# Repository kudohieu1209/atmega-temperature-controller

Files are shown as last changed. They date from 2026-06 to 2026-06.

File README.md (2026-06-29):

# ATmega16 Temperature Controller (LM35)

Bộ điều khiển nhiệt độ dùng vi điều khiển **ATmega16** và cảm biến **LM35**, viết bằng
**CodeVisionAVR**. Đọc nhiệt độ qua ADC, hiển thị lên LCD 16x2, và tự động bật/tắt
**quạt** và **đèn** qua relay theo ngưỡng nhiệt độ cài đặt.

## Tính năng

- Đọc nhiệt độ thực tế qua **ADC0 (PA0)** từ cảm biến **LM35** (10 mV/°C), Vref nội
  2.56V, độ phân giải 8-bit.
- **Mẹo thang đo:** `2.56V / 256 = 10 mV = đúng 1°C mỗi bước ADC`, nên giá trị `ADCH`
  đọc ra **chính là nhiệt độ °C** (dải 0–255 phủ tốt 0–100°C) — không cần công thức quy đổi.
- Hiển thị nhiệt độ **thực tế** và nhiệt độ **cài đặt** trên LCD 16x2.
- Điều khiển relay:
  - `temp > ngưỡng` → **bật quạt**, tắt đèn (làm mát).
  - `temp <= ngưỡng` → tắt quạt, **bật đèn** (sưởi).
- Cài đặt ngưỡng bằng 3 nút: UP / DOWN / RESET.
- Lưu ngưỡng cài đặt vào **EEPROM** → giữ nguyên sau khi mất điện.

## Sơ đồ chân

| Chân  | Chức năng |
|---|---|
| PA0 | Đầu vào ADC (cảm biến nhiệt độ) |
| PB0 | Nút UP — tăng ngưỡng |
| PB1 | Nút DOWN — giảm ngưỡng |
| PB2 | Relay FAN (quạt) — output |
| PB3 | Relay LIGHT (đèn) — output |
| PB4 | Nút RESET — về mặc định (25°C) |
| PORTC/PORTD | LCD 16x2 (theo cấu hình CodeWizard) |

> PB0, PB1, PB4 dùng điện trở kéo lên nội (active-low — nhấn = mức 0).

## Sơ đồ mạch (Proteus)

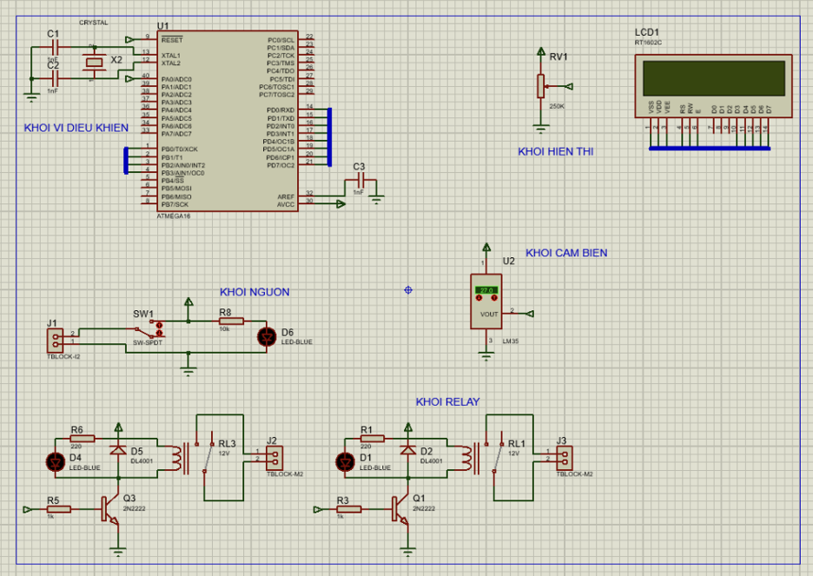
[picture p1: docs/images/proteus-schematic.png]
Sơ đồ mạch Proteus


Sơ đồ gồm các khối: vi điều khiển (ATmega16 + thạch anh), hiển thị (LCD1602 +
biến trở chỉnh tương phản), cảm biến (LM35), nguồn (công tắc + LED báo) và relay
(2 relay 12V kích qua transistor 2N2222 cho quạt/đèn).

File thiết kế PCB/sơ đồ nguyên lý gốc (Altium Designer) nằm trong
[`altium_schematic/`](altium_schematic/):

- `Sheet2.SchDoc` — sơ đồ nguyên lý
- `PCB2.PcbDoc` — layout mạch in

## Cấu trúc thư mục

```
atmega-temperature-controller/
├── README.md
├── src/
│   └── main.c                  # Mã nguồn chính
├── docs/
│   ├── hardware.md             # Mô tả phần cứng & ghi chú
│   └── images/
│       └── proteus-schematic.png   # Sơ đồ nguyên lý Proteus
└── altium_schematic/
    ├── Sheet2.SchDoc            # Sơ đồ nguyên lý (Altium Designer)
    └── PCB2.PcbDoc              # Layout PCB (Altium Designer)
```

## Biên dịch

Dự án dùng các thư viện riêng của CodeVisionAVR (`io.h`, `alcd.h`, `delay.h`).

1. Mở **CodeVisionAVR**, tạo project mới (hoặc dùng CodeWizardAVR).
2. Chọn chip **ATmega16** (kit hỗ trợ cả ATmega32 cùng chân đế) và tần số thạch anh.
3. Thêm `src/main.c` vào project.
4. Cấu hình LCD theo bảng chân ở trên, bật ADC với Vref nội 2.56V, ADLAR.
5. Build → nạp file `.hex` xuống chip (qua USBasp / mô phỏng Proteus).

## Ghi chú

- Với cấu hình **Vref 2.56V + 8-bit + LM35**, `ADCH` đọc ra trực tiếp là °C
  (1 LSB = 10 mV = 1°C). Nếu đổi Vref hoặc cảm biến khác thì phải đổi công thức quy đổi.
- LM35 chỉ đo dương (0°C trở lên); cấp nguồn 5V cho LM35, chân OUT nối PA0/ADC0.
- Ký tự `°` dùng mã `\xDF` của bộ ký tự HD44780 trên LCD.

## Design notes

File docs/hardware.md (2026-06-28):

# Phần cứng & Ghi chú kỹ thuật

## Sơ đồ nguyên lý
Xem sơ đồ mô phỏng Proteus tại [images/proteus-schematic.png](images/proteus-schematic.png):
các khối vi điều khiển, hiển thị (LCD1602), cảm biến (LM35), nguồn và relay.

## Khối nguồn / vi điều khiển
- MCU: **ATmega16** (kit AVR hỗ trợ cả ATmega32 cùng chân đế).
- Thạch anh ngoài tùy chọn; cấu hình tần số khớp với `delay.h`.

## Khối cảm biến — LM35
- Cảm biến nhiệt độ analog tuyến tính, hệ số **10 mV/°C** (vd. 250 mV = 25°C).
- Chân: `1 = VCC (5V)`, `2 = OUT → PA0/ADC0`, `3 = GND`.
- Chỉ đo dải dương (≥ 0°C); đầu ra trở kháng thấp, nối thẳng vào ADC được.

## Khối ADC (đọc LM35)
- Kênh: **ADC0 (PA0)**.
- Vref: nội bộ **2.56V** (`REFS1=1, REFS0=1`).
- `ADLAR = 1` → kết quả căn trái, đọc 8-bit từ thanh ghi `ADCH`.
- Prescaler: `ADPS2 | ADPS1` = chia 64.
- **Thang đo trực tiếp:** `2.56V / 256 = 10 mV = 1°C/LSB`, trùng đúng hệ số LM35,
  nên `temp = ADCH` cho ra °C mà không cần nhân/chia.

## Khối hiển thị
- LCD ký tự **16x2** (HD44780), thư viện `alcd.h`.
- Khởi tạo: `lcd_init(16)`.
- Ký tự độ `°` = mã `\xDF`.

## Khối nút bấm (active-low, pull-up nội)
| Nút | Chân | Hành vi |
|---|---|---|
| UP | PB0  | `m++`, vượt 99 → quay về 0 |
| DOWN  | PB1  | `m--`, dưới 0 → quay lên 99 |
| RESET | PB4  | `m = 25` (mặc định) |

- Chống dội phím: kiểm tra lại sau `20 ms`, chờ nhả nút (`while (btn == 0)`).
- Mỗi lần đổi giá trị → ghi ngay vào EEPROM địa chỉ 0.

## Khối relay đầu ra
| Tải | Chân | Logic |
|---|---|---|
| FAN | PB2  | `1` khi `temp > m` (quá nóng → làm mát)  |
| LIGHT | PB3  | `1` khi `temp <= m` (đủ mát → sưởi/đèn)  |

> Tùy module relay (kích mức cao hay thấp) có thể cần đảo logic ở `out_relay()`.

## EEPROM
- Địa chỉ `0`: lưu ngưỡng nhiệt độ cài đặt `m`.
- Đọc lúc khởi động; nếu giá trị > 99 (chưa khởi tạo) → đặt mặc định 25.

## Hướng nâng cấp gợi ý
- Thêm vùng trễ (hysteresis) để relay không đóng/ngắt liên tục quanh ngưỡng.
- Lấy trung bình nhiều mẫu ADC để giảm nhiễu trước khi so sánh ngưỡng.
- Tách `lcd_display()` thành hàm riêng để `main()` gọn hơn.
- Đo dải nhiệt độ cao hơn 100°C: chuyển Vref sang AVCC (5V) và đổi công thức quy đổi.

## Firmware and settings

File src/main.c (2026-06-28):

/*
 * Temperature Controller - ATmega16 + LM35 + CodeVisionAVR
 * --------------------------------------------------
 * Doc nhiet do qua ADC (cam bien LM35 tren ADC0, Vref 2.56V -> 1 LSB = 1 do C),
 * hien thi nhiet do thuc te + nhiet do cai dat tren LCD 16x2.
 * Dieu khien QUAT (FAN) va DEN (LIGHT) qua relay theo nguong cai dat.
 * Nhiet do cai dat luu trong EEPROM, chinh bang nut UP/DOWN/RESET.
 *
 * Chan ket noi:
 *   PB0 - nut UP    (tang nhiet do cai dat)
 *   PB1 - nut DOWN  (giam nhiet do cai dat)
 *   PB2 - relay FAN  (quat)
 *   PB3 - relay LIGHT (den)
 *   PB4 - nut RESET (dua cai dat ve 25)
 *   PA0 - dau vao ADC (chan OUT cua LM35)
 *   PORTC/PORTD - LCD 16x2 (theo cau hinh CodeWizard)
 */

#include <io.h>
#include <alcd.h>
#include <delay.h>

// Dinh nghia chan nut bam va relay
#define UP        PINB.0
#define DW        PINB.1
#define RESET_BTN PINB.4   // Nut RESET dau vao PB4
#define FAN       PORTB.2
#define LIGHT     PORTB.3

// VREF noi bo 2.56V + ADLAR=1 (8-bit)
#define ADC_VREF_TYPE  ((1<<REFS1) | (1<<REFS0) | (1<<ADLAR))

// Hang so cau hinh
#define TEMP_DEFAULT   25   // Nhiet do cai dat mac dinh
#define TEMP_MAX       99   // Gioi han tren nhiet do cai dat
#define EEPROM_ADDR_M   0   // Dia chi EEPROM luu nhiet do cai dat
#define DEBOUNCE_MS    20   // Thoi gian chong doi nut bam

unsigned char temp = 0;
unsigned char m = TEMP_DEFAULT;   // Nhiet do cai dat hien tai

// EEPROM
void EEPROM_write(unsigned int uiAddress, unsigned char ucData)
{
    while (EECR & (1<<EEWE));
    EEAR = uiAddress;
    EEDR = ucData;
    EECR |= (1<<EEMWE);
    EECR |= (1<<EEWE);
    while (EECR & (1<<EEWE));
}

unsigned char EEPROM_read(unsigned int uiAddress)
{
    while (EECR & (1<<EEWE));
    EEAR = uiAddress;
    EECR |= (1<<EERE);
    return EEDR;
}

// ADC
unsigned char read_adc(unsigned char adc_input)
{
    ADMUX = adc_input | ADC_VREF_TYPE;
    delay_us(10);
    ADCSRA |= (1<<ADSC);
    while ((ADCSRA & (1<<ADIF)) == 0);
    ADCSRA |= (1<<ADIF);
    return ADCH;
}

void ADC_init(void)
{
    ADMUX = ADC_VREF_TYPE;
    ADCSRA = (1<<ADEN) | (1<<ADPS2) | (1<<ADPS1);
}

// Nut bam
void button(void)
{
    // Nut UP (tang nhiet do)
    if (UP == 0)
    {
        delay_ms(DEBOUNCE_MS);
        if (UP == 0)
        {
            m++;
            if (m > TEMP_MAX) m = 0;
            EEPROM_write(EEPROM_ADDR_M, m);
            while (UP == 0);
        }
    }

    // Nut DOWN (giam nhiet do)
    if (DW == 0)
    {
        delay_ms(DEBOUNCE_MS);
        if (DW == 0)
        {
            if (m == 0) m = TEMP_MAX;
            else m--;
            EEPROM_write(EEPROM_ADDR_M, m);
            while (DW == 0);
        }
    }

    // Nut RESET (dua nhiet do cai dat ve mac dinh)
    if (RESET_BTN == 0)
    {
        delay_ms(DEBOUNCE_MS);
        if (RESET_BTN == 0)
        {
            m = TEMP_DEFAULT;
            EEPROM_write(EEPROM_ADDR_M, m);
            while (RESET_BTN == 0);
        }
    }
}

// Dieu khien relay
void out_relay(void)
{
    if (temp > m)
    {
        FAN = 1;      // Bat quat
        LIGHT = 0;    // Tat den
    }
    else
    {
        FAN = 0;      // Tat quat
        LIGHT = 1;    // Bat den
    }
}

void main(void)
{
    // Khoi tao LCD 16x2
    lcd_init(16);

    // Khoi tao ADC
    ADC_init();

    // Cau hinh PORT
    DDRA = 0x00;                // PORTA input cho ADC
    DDRB = 0xFC;                // PB2, PB3 output; PB0, PB1, PB4 input
    PORTB = 0x13;               // Pull-up noi cho PB0, PB1, PB4 (0b00010011)
    DDRD = 0xFF;

    // Doc nhiet do cai dat tu EEPROM
    m = EEPROM_read(EEPROM_ADDR_M);
    if (m > TEMP_MAX) m = TEMP_DEFAULT;

    while (1)
    {
        temp = read_adc(0);

        // Hien thi nhiet do thuc te
        lcd_gotoxy(0, 0);
        lcd_puts("NHIET DO: ");
        lcd_gotoxy(10, 0);
        lcd_putchar(0x30 + temp/10);
        lcd_putchar(0x30 + temp%10);
        lcd_gotoxy(13, 0);
        lcd_puts("\xDF" "C ");

        // Hien thi nhiet do cai dat
        lcd_gotoxy(0, 1);
        lcd_puts("CAI DAT : ");
        lcd_gotoxy(10, 1);
        lcd_putchar(0x30 + m/10);
        lcd_putchar(0x30 + m%10);
        lcd_gotoxy(13, 1);
        lcd_puts("\xDF" "C ");

        out_relay();
        button();

        delay_ms(150);
    }
}

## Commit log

2026-06-28 feat: ATmega16 + LM35 temperature controller (CodeVision)
    LCD 16x2 display, fan/light relay control by setpoint,
    UP/DOWN/RESET buttons, setpoint saved in EEPROM.
    [PCB2.PcbDoc, Sheet2.SchDoc]
2026-06-28 docs: add Proteus schematic image and reference it in README/hardware
